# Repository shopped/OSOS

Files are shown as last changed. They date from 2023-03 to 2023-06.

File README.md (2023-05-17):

# Open Source Open Sign (for crashspace.org)

There is a button to indicate if somebody is at crash space, which is a non profit community maker space.

Picture of button

When you press the button it will update the website showing that the space is open for the next hour. 

This code repository is the software and hardware information for a sign that will sync to the open status of the space. 

Here is how the sign will look when nobody is at the space.

Picture of sign turned off

And if somebody presses the button, the sign will light up and look like this.

Picture of sign turned on

Below is a picture of the internals and a bill of materials. This repository is free and open source under GNU GPLv3

Picture of internals

## Bill of Materials

- NeoPixel Stick: Adafruit 1426
- 2x NeoPixel Ring 12: Adafruit 1643
- 3mm one way glass cut to 181mm x 79mm
- QT Py ESP32-S2: Adafruit P5325
- 4 Screws M3x8 (Face Plate)
- 2 Screws M2x8 (LED mounting)
- 2-4 Screws M2x12 (Chip mounting)
- USB-C Power Cable
- Electrical wire
- Fishing wire

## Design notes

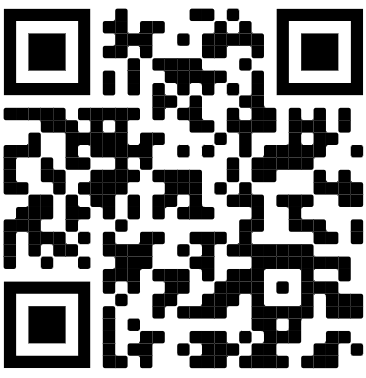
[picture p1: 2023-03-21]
OSOS QR.png

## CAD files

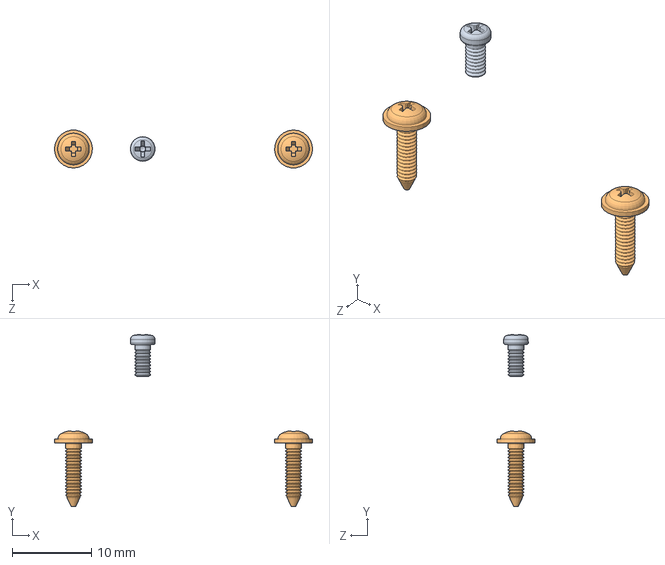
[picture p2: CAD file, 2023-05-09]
CADfiles/sg90-micro-servo-9g-tower-pro-1.snapshot.3/SG90 - Micro Servo 9g - Tower Pro.SLDASM
32.6 x 21.7 x 4.80 mm
SG90 - Micro Servo 9g - Tower Pro.5 x 2
SG90 - Micro Servo 9g - Tower Pro.6

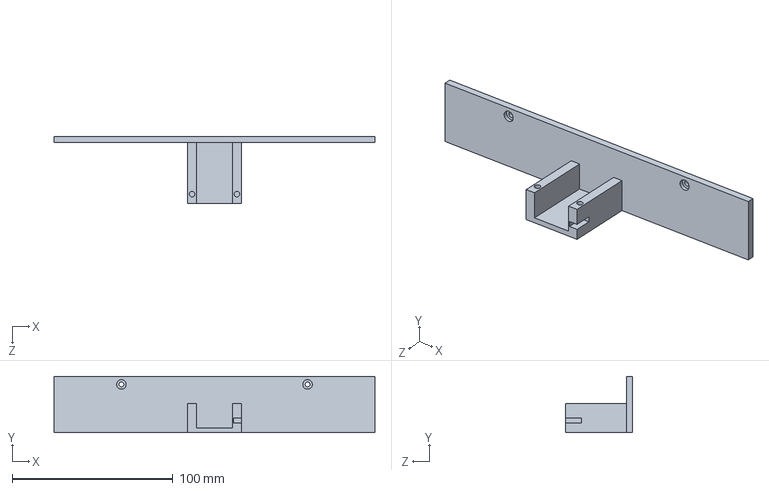
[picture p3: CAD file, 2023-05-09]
CADfiles/Abandoned Motor Design/MotorMount.SLDPRT
200.0 x 35.0 x 42.0 mm

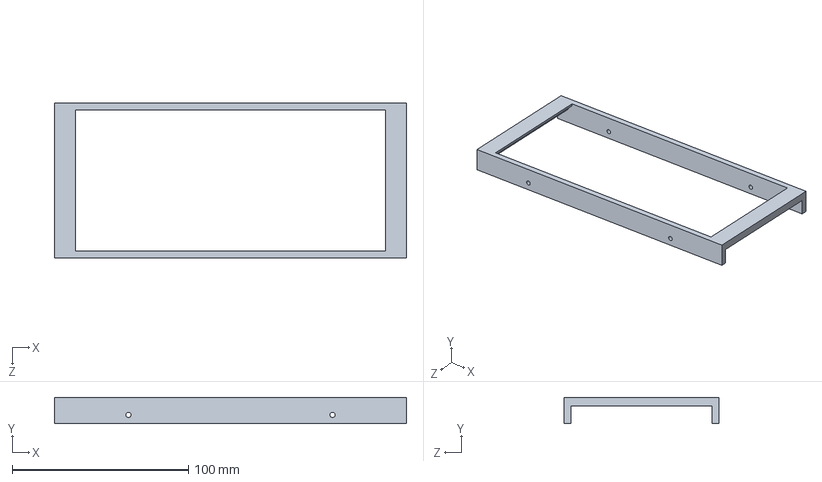
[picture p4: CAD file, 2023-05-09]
CADfiles/CoverRails.SLDPRT
200.0 x 15.0 x 88.0 mm

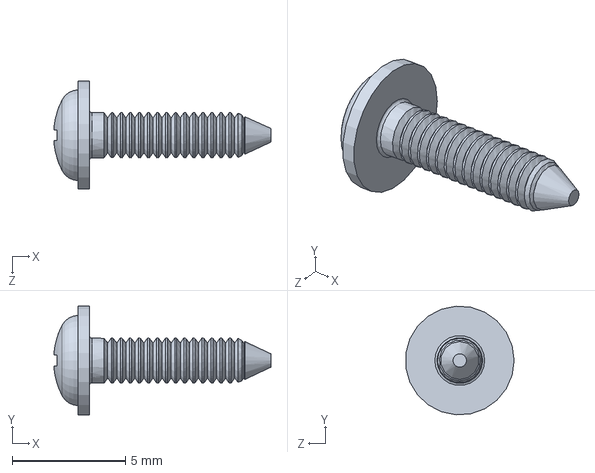
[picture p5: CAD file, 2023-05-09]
CADfiles/sg90-micro-servo-9g-tower-pro-1.snapshot.3/SG90 - Micro Servo 9g - Tower Pro.5.SLDPRT
9.57 x 4.79 x 4.78 mm

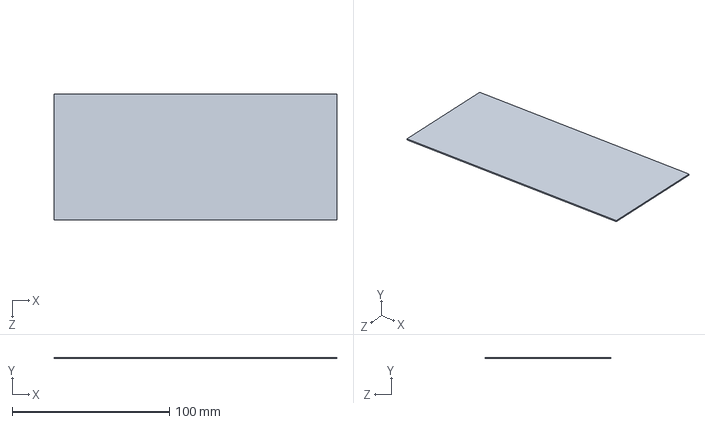
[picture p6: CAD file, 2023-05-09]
CADfiles/Abandoned Motor Design/FacePlateCover.SLDPRT
180.0 x 0.9 x 80.0 mm

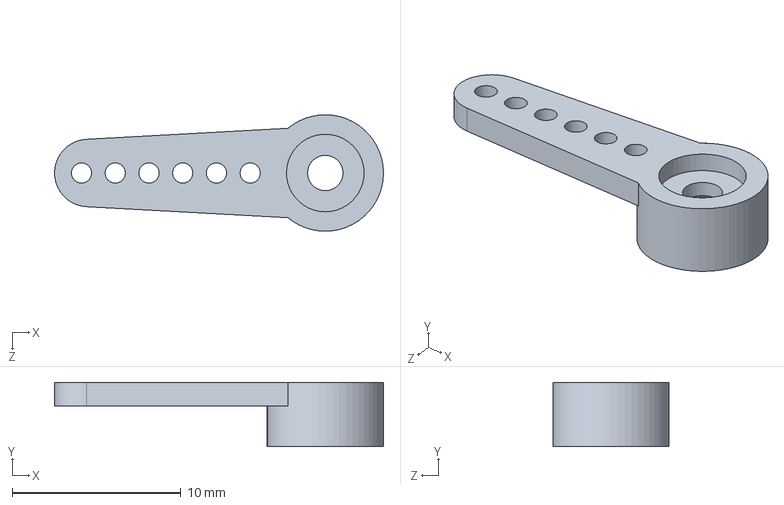
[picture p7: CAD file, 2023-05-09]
CADfiles/sg90-micro-servo-9g-tower-pro-1.snapshot.3/SG90 - Micro Servo 9g - Tower Pro.2.SLDPRT
19.5 x 3.80 x 6.90 mm

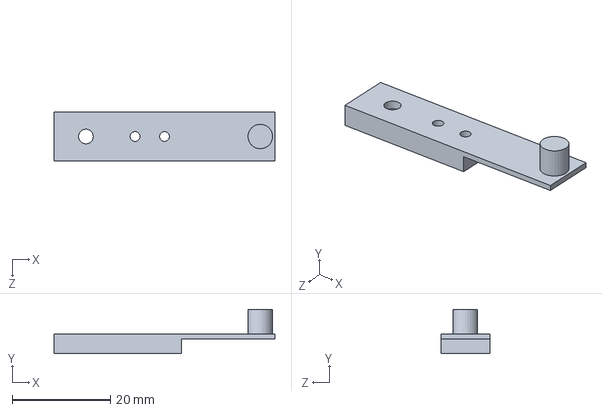
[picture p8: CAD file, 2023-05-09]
CADfiles/Abandoned Motor Design/PushArm.SLDPRT
45.0 x 9.00 x 10.0 mm

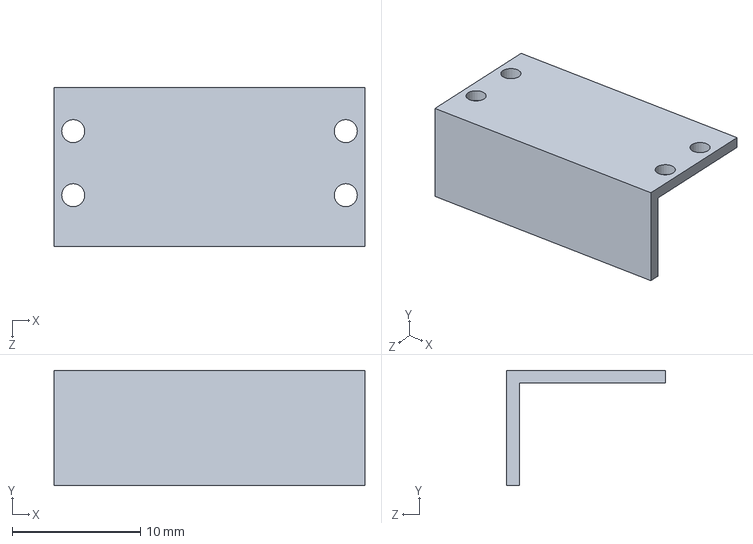
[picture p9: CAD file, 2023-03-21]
CADfiles/ChipCap.SLDPRT
24.3 x 9.00 x 12.4 mm

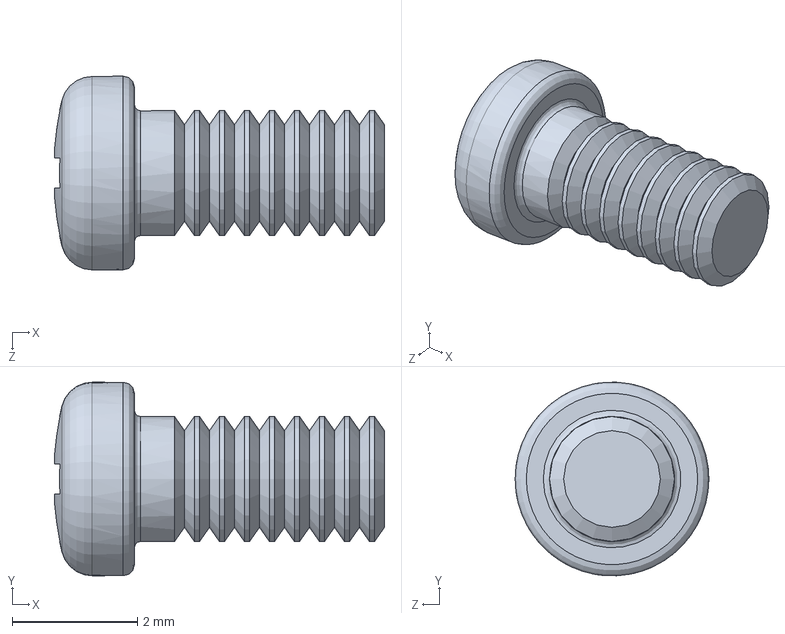
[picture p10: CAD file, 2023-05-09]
CADfiles/sg90-micro-servo-9g-tower-pro-1.snapshot.3/SG90 - Micro Servo 9g - Tower Pro.6.SLDPRT
5.28 x 3.10 x 3.10 mm

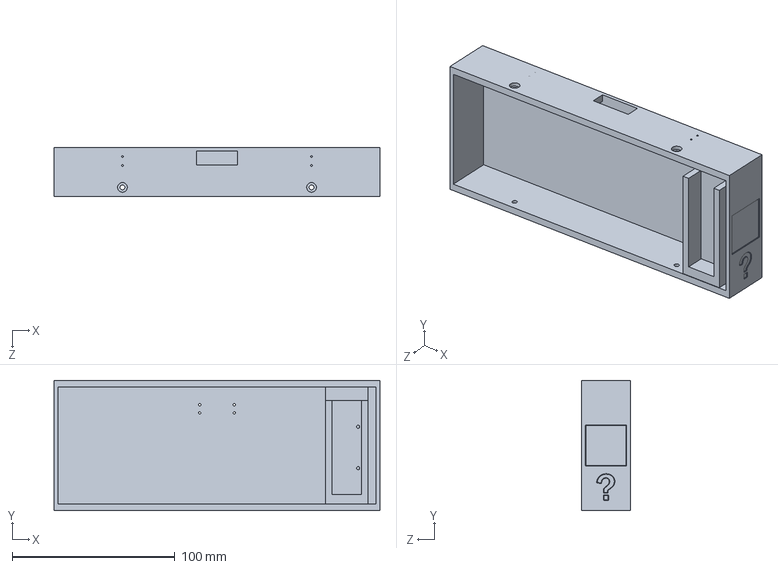
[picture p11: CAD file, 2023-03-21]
CADfiles/ElectronicsEnclosure.SLDPRT
200.0 x 80.0 x 29.9 mm

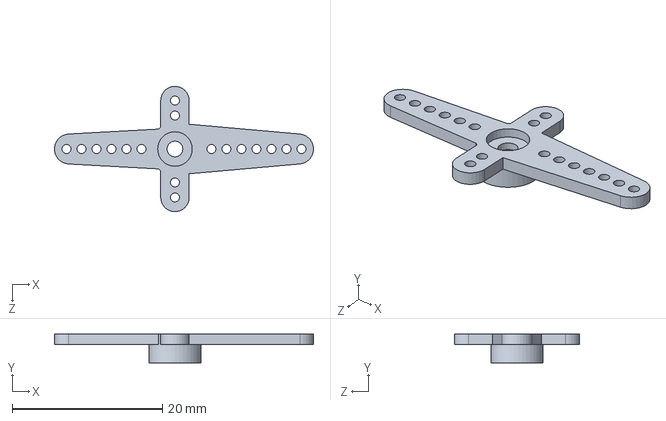
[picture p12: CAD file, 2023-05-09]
CADfiles/sg90-micro-servo-9g-tower-pro-1.snapshot.3/SG90 - Micro Servo 9g - Tower Pro.4.SLDPRT
34.5 x 3.80 x 16.7 mm

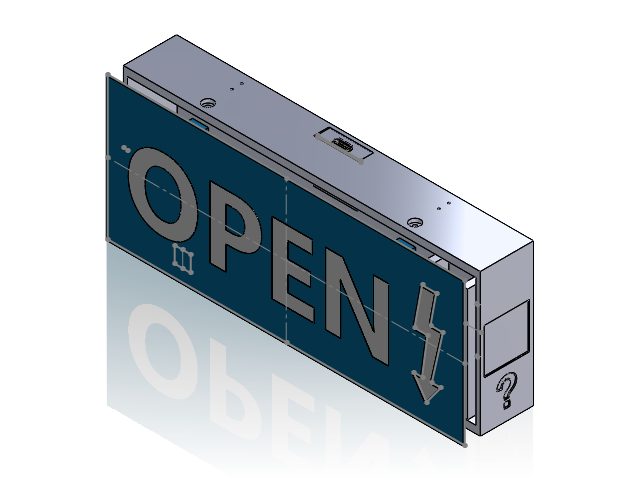
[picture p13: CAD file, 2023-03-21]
CADfiles/OpenSign.SLDASM
ElectronicsEnclosure
FacePlate
ChipCap
ChipBracket
Board
22uF x 3
reset
USB TYPE C
1k x 18
STEMMA_I2C_QTSKINNY
AP2112K-3.3
WS2812B_SK6805_1515
NSR0320 x 2
0 ohm x 2
40MHz
2.4GHz
BOOT0
ESP32-C3FH4
10K

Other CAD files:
CADfiles/chip/PCB Component.SLDASM
CADfiles/chip/PCB Component_2.SLDASM
CADfiles/chip/AP2112K-3.3.SLDPRT
CADfiles/chip/10K_2.SLDPRT
CADfiles/chip/40MHz.SLDPRT
CADfiles/chip/22uF.SLDPRT
CADfiles/ChipBracket.SLDPRT
CADfiles/FacePlate.SLDPRT
CADfiles/chip/ NSR0320.SLDPRT
CADfiles/chip/ NSR0320_2.SLDPRT
CADfiles/chip/0 ohm.SLDPRT
CADfiles/chip/0 ohm_2.SLDPRT
CADfiles/chip/10K.SLDPRT
CADfiles/chip/1k.SLDPRT
CADfiles/chip/1k_2.SLDPRT
CADfiles/chip/2.4GHz.SLDPRT
CADfiles/chip/2.4GHz_2.SLDPRT
CADfiles/chip/40MHz_2.SLDPRT
CADfiles/chip/AP2112K-3.3_2.SLDPRT
CADfiles/chip/BOOT0.SLDPRT
CADfiles/chip/BOOT0_2.SLDPRT
CADfiles/chip/Board.SLDPRT
CADfiles/chip/ESP32-C3FH4.SLDPRT
CADfiles/chip/ESP32-C3FH4_2.SLDPRT
CADfiles/chip/STEMMA_I2C_QTSKINNY.SLDPRT
CADfiles/chip/STEMMA_I2C_QTSKINNY_2.SLDPRT
CADfiles/chip/USB TYPE C.SLDPRT
CADfiles/chip/WS2812B_SK6805_1515.SLDPRT
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

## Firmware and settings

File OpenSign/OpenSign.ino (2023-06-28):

#include <FastLED.h>
#include <WiFi.h>
#include <HTTPClient.h>
#include <Adafruit_SleepyDog.h>

#define NUM_LEDS_LIGHTNING 8
#define NUM_LEDS_TEXT 24
#define LIGHTNING_BOLT_PIN 18
#define OPEN_TEXT_PIN 17

// MAJOR CONFIG
bool debug = false;
bool debugSetup = false;
bool demo = false;
bool demoColors = false;
const char* ssid = "";
const char* password = "";

// MINOR CONFIG
const int LOOP_TIME = 1000 * 60 * 2; // update sign every 2 minutes
const int RESET_TIME = 1000 * 60 * 5; // reboot device if nonresponsive for 5 minutes

// GET OPEN STATUS, DATE, AND TIME REMAINING
const char* serverName = "http://crashspacela.com/sign/";
const String statusSearchString = "Crash Space is OPEN";
const String timeSearchString = "The space will close in ";
const String dateSearchString = "<td>update</td><td> ";

// LED ARRAYS
CRGB lightning_leds[NUM_LEDS_LIGHTNING];
CRGB text_leds[NUM_LEDS_TEXT];

//uint32_t heapSize = ESP.getFreeHeap(); // for debugging

String getWebsiteText() {
  WiFiClient client;
  HTTPClient http;
  http.begin(client, serverName);
  int httpResponseCode = http.GET();
  
  String payload = "error"; // this will make the sign appear off if the site is unreachable
  
  if (httpResponseCode == 200) {
    payload = http.getString();
  }
  else if (debug) {
    Serial.print("Error code: ");
    Serial.println(httpResponseCode);
  }
  http.end();
  return payload;
}

bool isSpaceOpen(String websiteText) {
  if (websiteText.indexOf(statusSearchString)>0){
      return true;
  }
  return false;
}
String colorKeys[] = {"02-14", "03-17", "07-04", "12-24", "12-25"};
int colorValues[][3][3] = {
  {{200,90,90},{200,90,90},{200,90,90}},
  {{0,150,0},{0,150,0},{0,150,0}},
  {{180,0,0},{180,180,180},{0,0,180}},
  {{180,0,0},{0,180,0},{180,180,180}},
  {{180,0,0},{0,180,0},{180,180,180}}
};
int defaultColor[3][3] = {
  {200, 200, 200}, 
  {200, 200, 200}, 
  {100, 20, 0}
};
int currentColor[3][3];

void setCurrentColor(String websiteText) {
  int dateIndex = websiteText.indexOf(dateSearchString) + dateSearchString.length() + 5; // ignore year portion (2023-)
  String dateValue = websiteText.substring(dateIndex,dateIndex+5);
  memcpy(currentColor, defaultColor, sizeof(defaultColor[0][0])*9);
  for (int i=0; i<5; i++) {
    if (colorKeys[i] == dateValue) {
      memcpy(currentColor, colorValues[i], sizeof(defaultColor[0][0])*9);
    }
  }
}

void setOpenTextLights() {
  for (int i=0; i<NUM_LEDS_TEXT; i++) {
    if (i >= 12) {
      text_leds[i] = CRGB(currentColor[0][0], currentColor[0][1], currentColor[0][2]);
    } else {
      text_leds[i] = CRGB(currentColor[1][0], currentColor[1][1], currentColor[1][2]);
    }
  }
  FastLED.show();
}

void setLightningBoltLights(String websiteText) {
  int minutesRemainingIndex = websiteText.indexOf(timeSearchString) + timeSearchString.length();
  int minutesRemainingValue = websiteText.substring(minutesRemainingIndex, minutesRemainingIndex+2).toInt();
  int numberLit = ceil(8.0*(double(minutesRemainingValue)/60.0));
  
  for (int i=0; i<8; i++) {
    if (i < numberLit) {
      lightning_leds[7-i] = CRGB(currentColor[2][0], currentColor[2][1], currentColor[2][2]);
    } else {
      lightning_leds[7-i] = CRGB::Black;
    }
  }
  FastLED.show();
}

void setup()
{
  Watchdog.enable(RESET_TIME);
  
  if (debug) {
    Serial.begin(115200);
    if (debugSetup) {
      while (!Serial) {
        delay(10);
      }
    }
  }
  
  FastLED.addLeds<NEOPIXEL, LIGHTNING_BOLT_PIN>(lightning_leds, NUM_LEDS_LIGHTNING);
  FastLED.addLeds<NEOPIXEL, OPEN_TEXT_PIN>(text_leds, NUM_LEDS_TEXT);
  fill_solid(lightning_leds, NUM_LEDS_LIGHTNING, CRGB(0, 0, 0));
  fill_solid(text_leds, NUM_LEDS_TEXT, CRGB(0, 0, 0));
  FastLED.show();

  WiFi.begin(ssid, password);
  if (debug) {
    Serial.println("Connecting");
  }
  while(WiFi.status() != WL_CONNECTED) {
    delay(500);
    if (debug) {
      Serial.print((wl_status_t) WiFi.status());
      Serial.println("/ connecting...");
    }
  }
}

void demoLoop() {
  fill_solid(lightning_leds, NUM_LEDS_LIGHTNING, CRGB(150, 30, 0));
  fill_solid(text_leds, NUM_LEDS_TEXT, CRGB(180, 180, 180));
  FastLED.show();
  delay(1000);

  if (demoColors) {
    for (int i=0; i<5;i++) {
      memcpy(currentColor, colorValues[i], sizeof(defaultColor[0][0])*9);
      setOpenTextLights();
      setLightningBoltLights("Space will close in 60 minutes");
      delay(500);
    }
  }
  
  fill_solid(lightning_leds, NUM_LEDS_LIGHTNING, CRGB(0, 0, 0));
  fill_solid(text_leds, NUM_LEDS_TEXT, CRGB(0, 0, 0));
  FastLED.show();
  delay(1000);
}

void loop()
{
  if (demo) {
    demoLoop();
    return;
  }
  String websiteText = getWebsiteText();
  if (debug) {
    Serial.println(isSpaceOpen(websiteText) ? "Crash is open" : "Crash is closed");
  }
  if (isSpaceOpen(websiteText)) {  
    setCurrentColor(websiteText);
    setOpenTextLights();
    setLightningBoltLights(websiteText);
  } else {
    fill_solid(lightning_leds, NUM_LEDS_LIGHTNING, CRGB(0, 0, 0));
    fill_solid(text_leds, NUM_LEDS_TEXT, CRGB(0, 0, 0));
    FastLED.show();
  }
  Watchdog.reset();
  delay(LOOP_TIME);
}

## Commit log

2023-03-21 CAD files and readme
    [NSR0320.SLDPRT, NSR0320_2.SLDPRT, 0 ohm.SLDPRT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]
2023-05-09 New CAD files and license
    [CoverRails.SLDPRT, FacePlateCover.SLDPRT, MotorMount.SLDPRT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]
2023-06-28 Watchdog reset, lights respond to holidays and remaining time
    [OpenSign.ino]
